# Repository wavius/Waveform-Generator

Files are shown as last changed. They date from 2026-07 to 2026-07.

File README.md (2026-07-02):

# Waveform-Generator

A power supply and waveform generator PCB. View the [Schematic and Layout (PDF)](./WAVEFORM_GENERATOR.pdf).

- +12V, -12V, +5V, and +3V3 DC power rails.
- Sine, square, and triangle signal outputs using the AD9833 IC.
- 45 W USB-C input for power delivery using the IP2721 IC.
- Integrated STM32F030C8T6 microcontroller for control.

<br>
<div align="left">
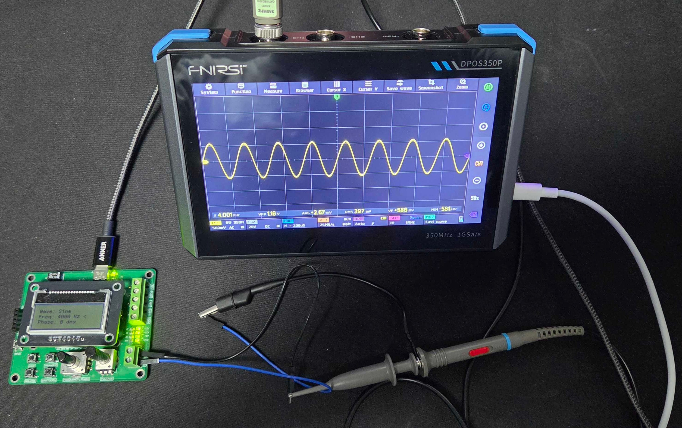
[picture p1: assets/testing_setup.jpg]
Testing Setup
  
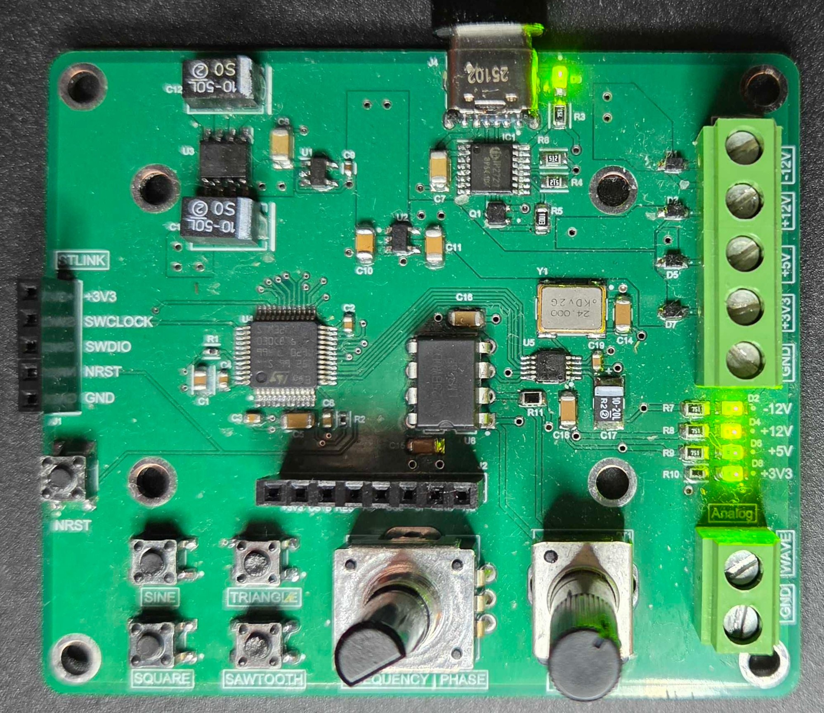
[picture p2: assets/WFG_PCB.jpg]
Waveform Generator Assembled PCB
  
</div>
<br>

## Features

### Power Supply

- **Screw Terminals**: +12V, -12V, +5V, and +3V3 DC power rails.

    <br>
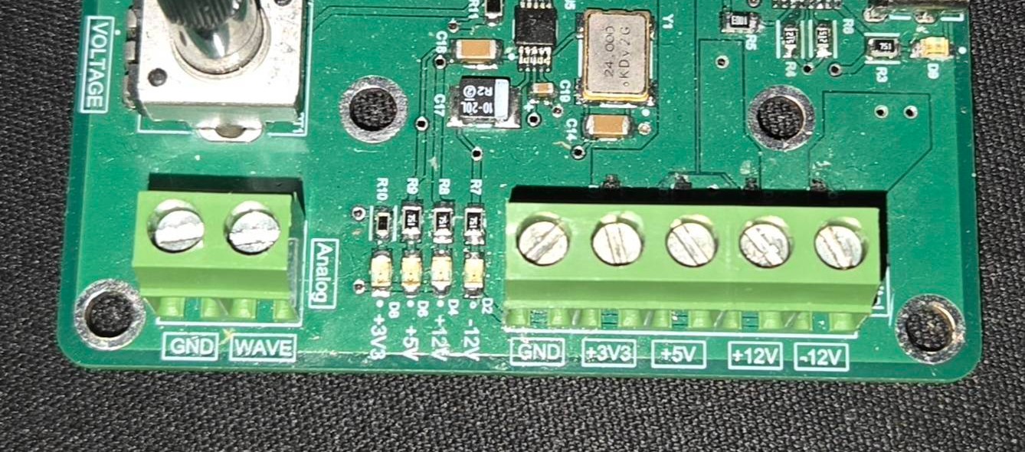
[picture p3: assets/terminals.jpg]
Screw Terminals
    
    <br>

### Signal Output

- **Waveform**: Toggle between sine, square, and triangle waveforms using the buttons. Note that the Sawtooth wave is unsupported by the AD9833 (oops), so the button toggles a half-frequency square wave instead.

    <br>
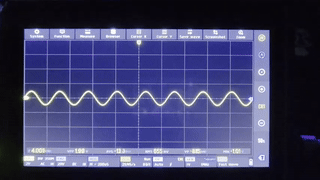
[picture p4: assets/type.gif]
Waveform Type
    
    <br>

- **Frequency and Phase**: Control the output frequency and phase using the rotary encoder.

    <br>
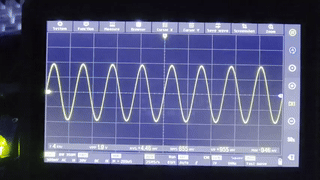
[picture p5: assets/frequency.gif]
Frequency Control
    
    <br>

- **Amplitude**: Tune the output analog voltage amplitude using the potentiometer.

    <br>
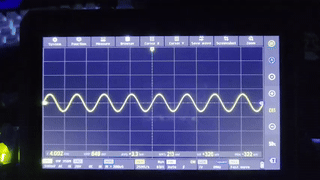
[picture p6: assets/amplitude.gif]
Amplitude Control
    
    <br>

### System Interface

- **Display**: LCD interface header for real-time waveform and parameter display.

    <br>
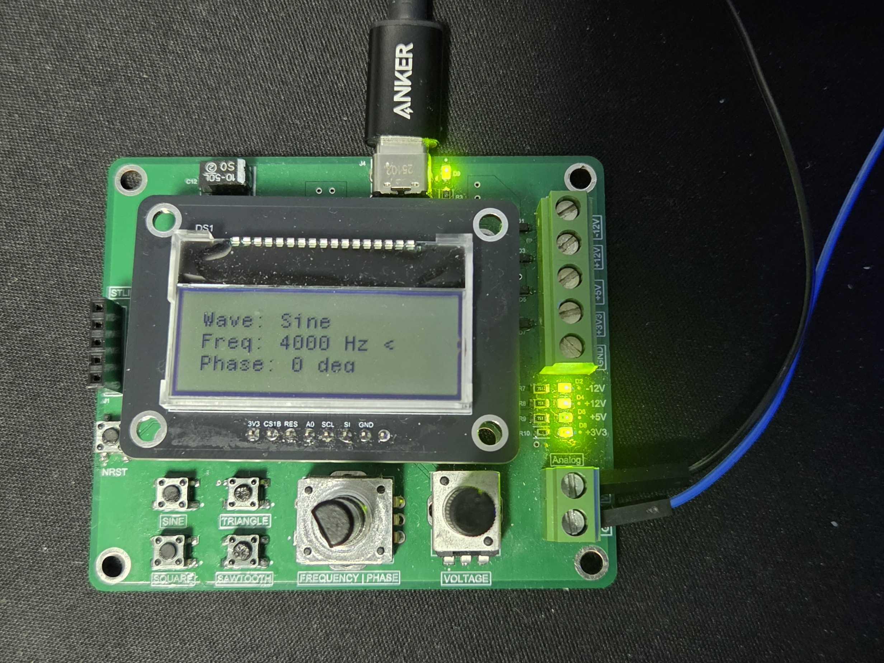
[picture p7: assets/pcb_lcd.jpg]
PCB LCD Display
    
    <br>

- **Control**: STM32F030C8T6 microcontroller with an ST-LINK interface header for programming and testing.

    <br>
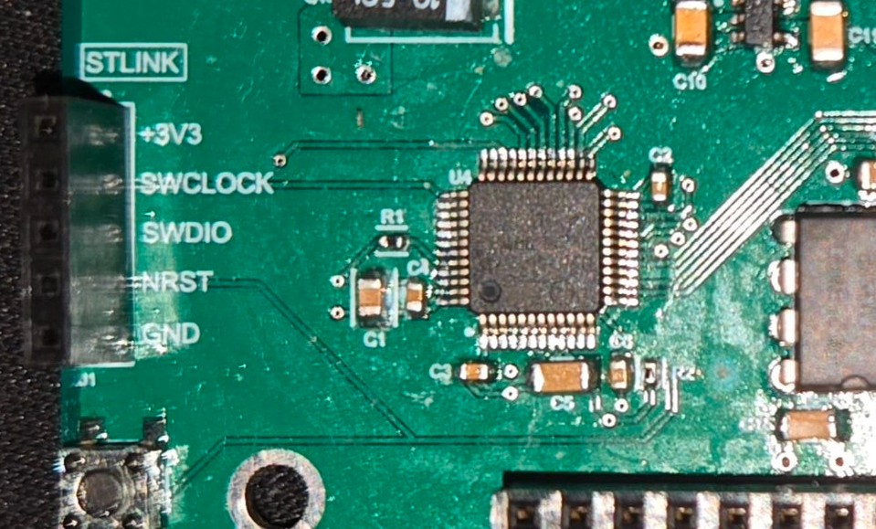
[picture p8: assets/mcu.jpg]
MCU
    
    <br>

## Source

### Firmware

The firmware is located in the [STM32 Project](./STM32%20Project) folder. It is written in C and uses the STM32 HAL libraries. Interrupts are used for the rotary encoder and buttons.

It can be opened and compiled using [STM32CubeIDE](https://www.st.com/en/development-tools/stm32cubeide.html). To upload the firmware to the device, use an ST-LINK V2, such as the one found on a NUCLEO board, and [STM32CubeProgrammer](https://www.st.com/en/development-tools/stm32cubeprogrammer.html).

### Design Files

The PCB design files are available in the [Altium Files](./Altium%20Files) folder. It is a 4-layer PCB with separate power and signal stages to minimize noise.

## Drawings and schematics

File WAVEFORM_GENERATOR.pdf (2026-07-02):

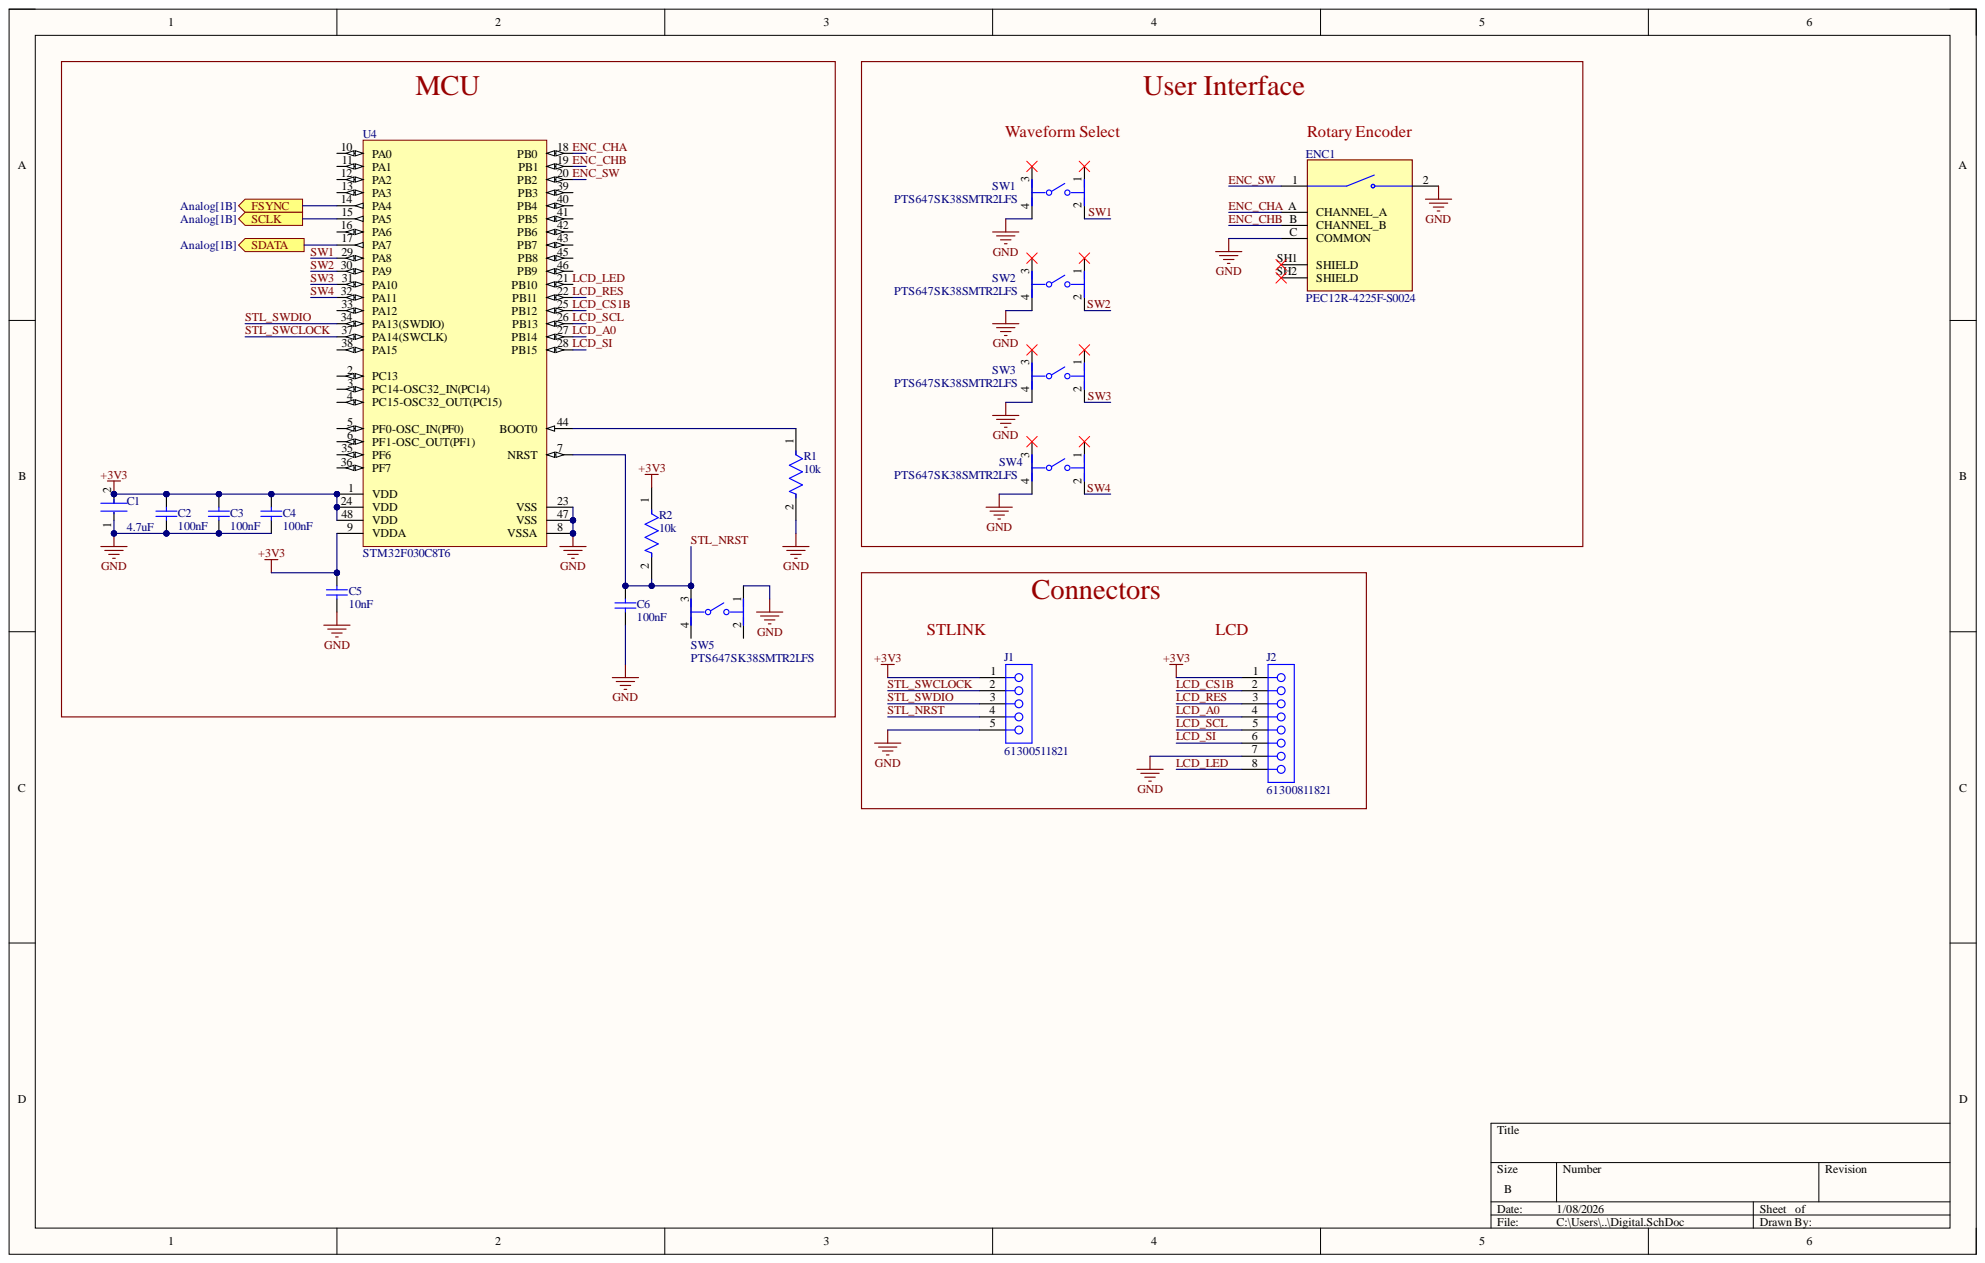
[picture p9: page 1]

2 4
4 8 | 4

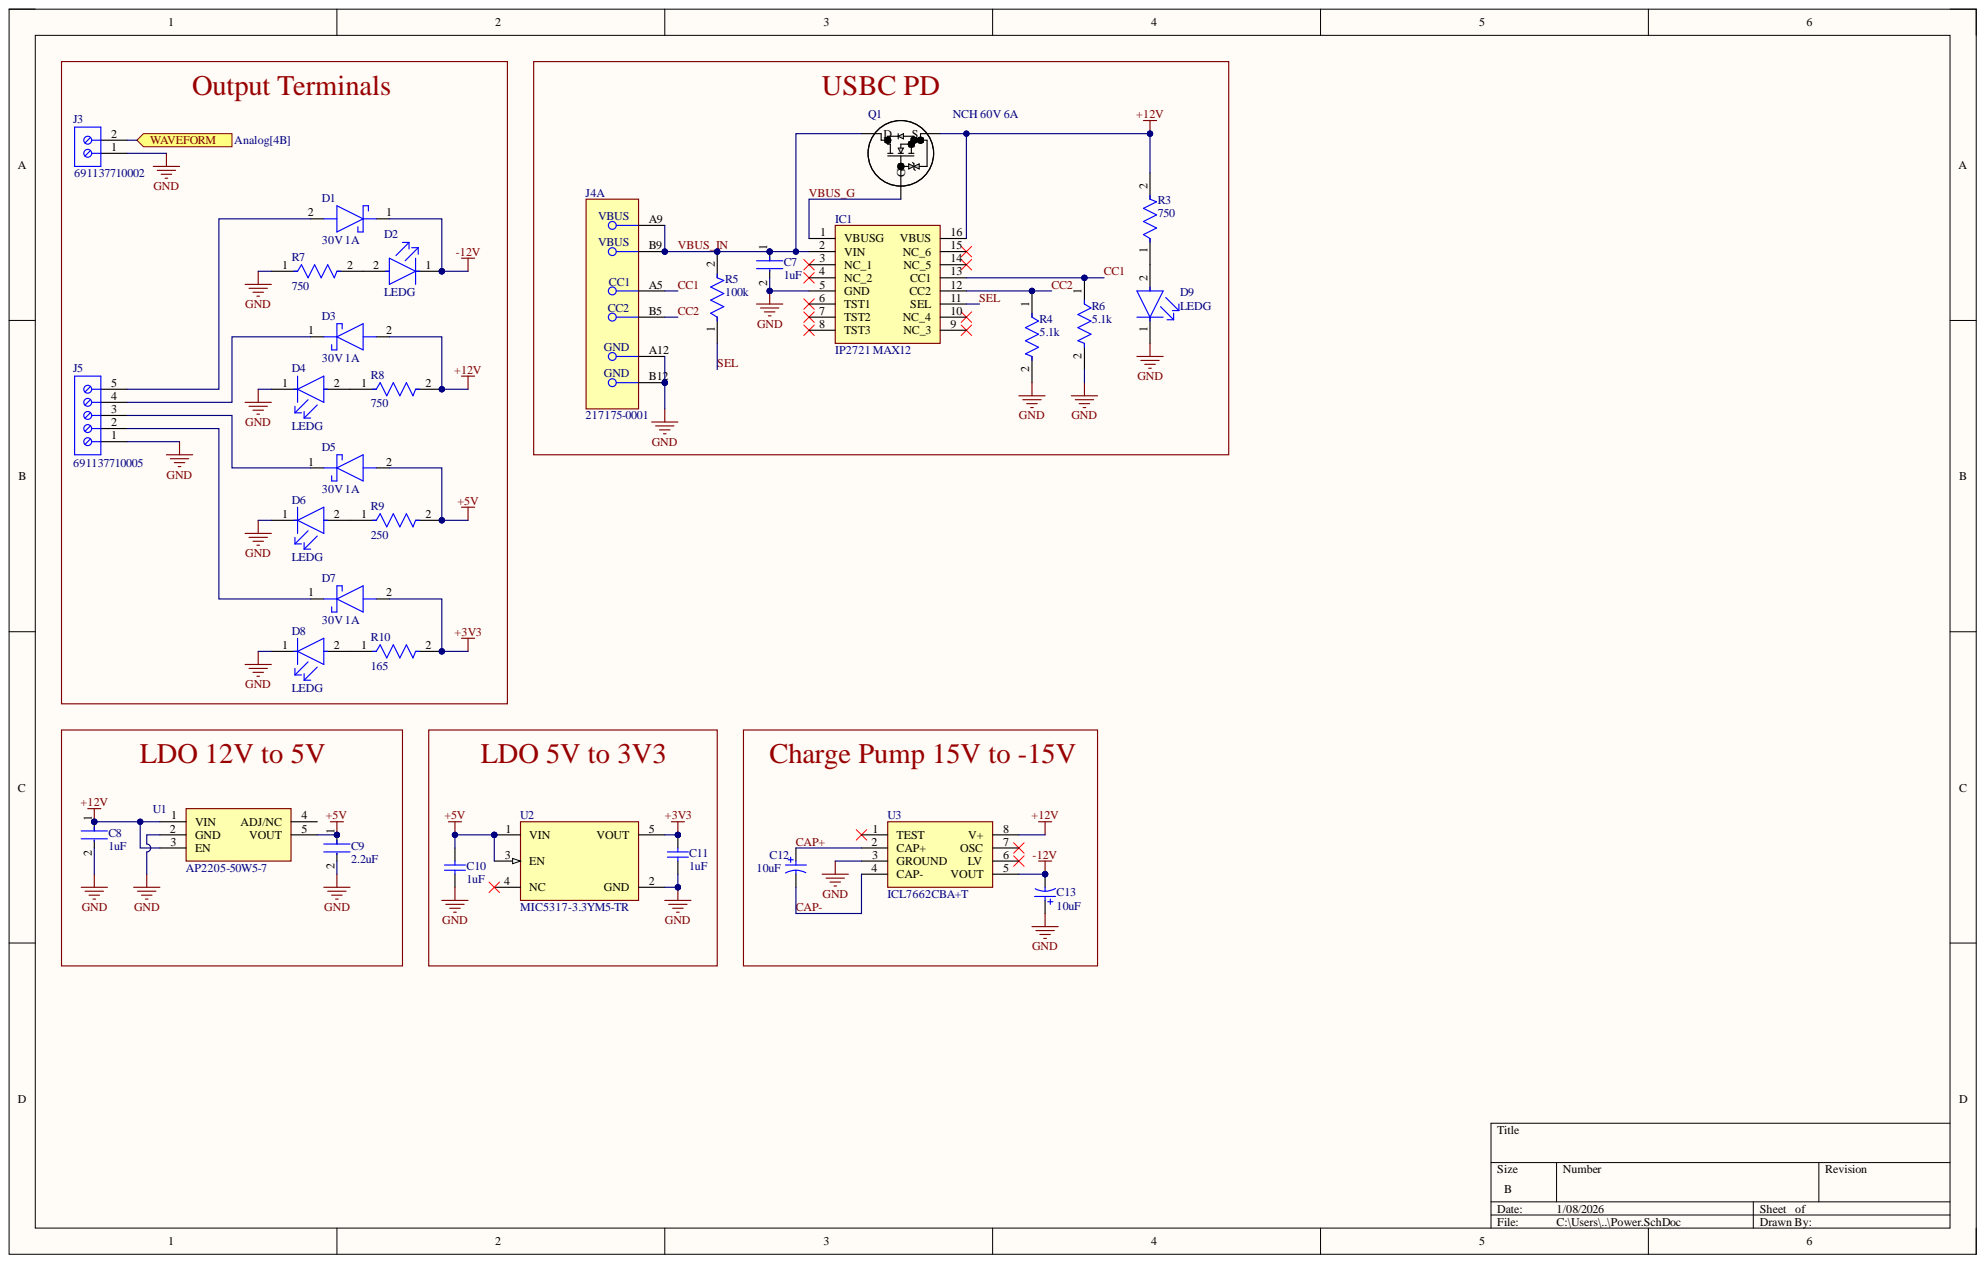
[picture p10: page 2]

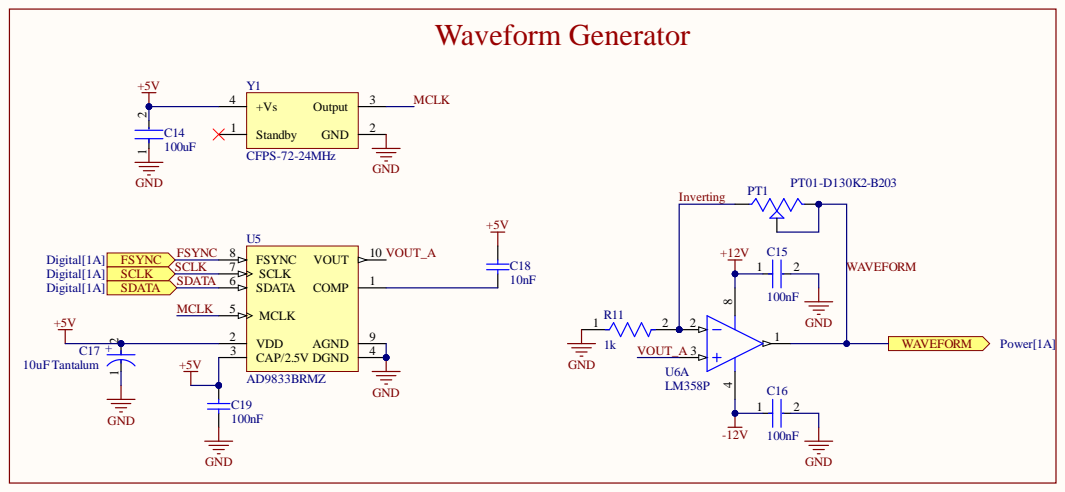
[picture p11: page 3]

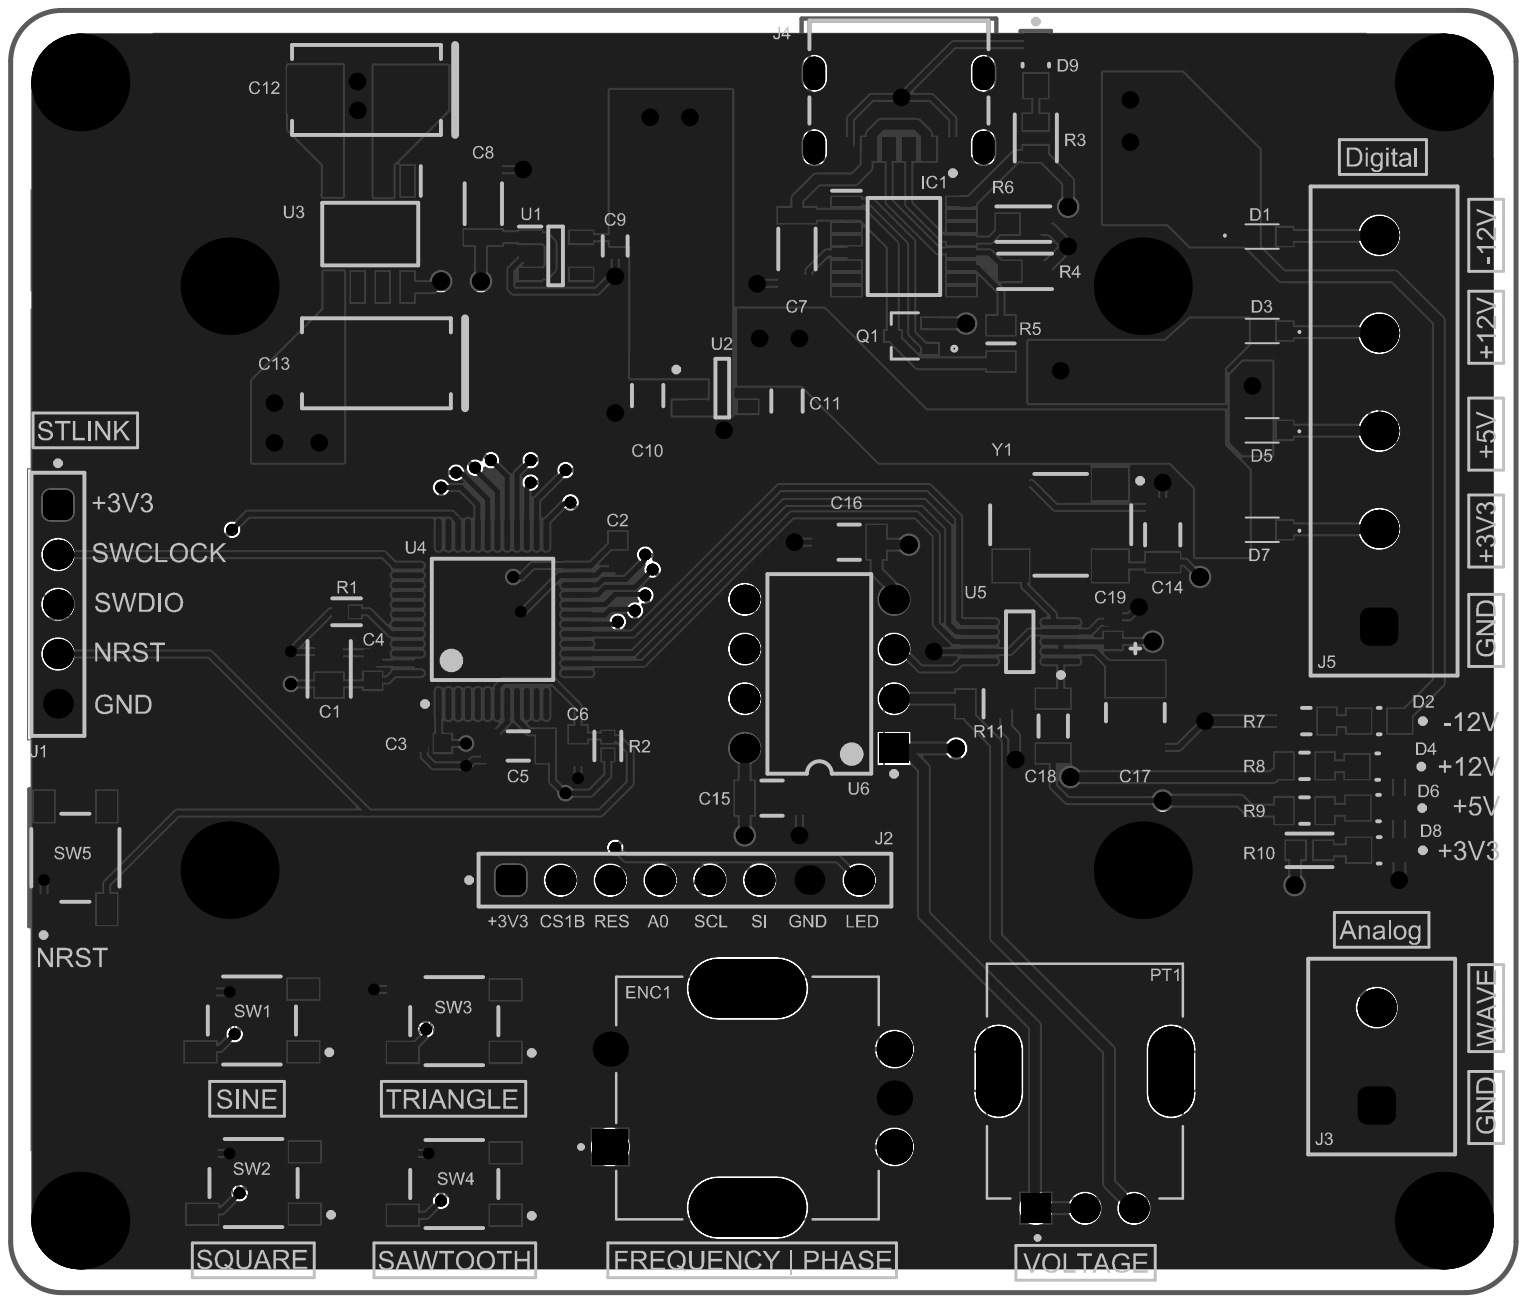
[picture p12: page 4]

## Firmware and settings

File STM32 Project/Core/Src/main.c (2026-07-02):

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
/* Includes ------------------------------------------------------------------*/
#include "main.h"

/* USER CODE BEGIN Includes */
#include "ad9833.h"
#include "st7565r.h"
#include <stdio.h>
/* USER CODE END Includes */

/* USER CODE BEGIN PTD */
enum Mode {
  MODE_FREQUENCY,
  MODE_PHASE
};
/* USER CODE END PTD */

/* USER CODE BEGIN PD */
#define AD9833_FREQ_MAX 100000ULL // 100 kHz
#define AD9833_FREQ_MIN 1ULL      // 1 Hz
#define AD9833_FREQ_STEP 1000ULL  // 1 kHz
/* USER CODE END PD */


/* USER CODE BEGIN PV */
uint32_t AD9833_Frequency = 1000; // 1 kHz
uint32_t AD9833_Phase = 0;        // 0 degrees
enum Mode AD9833_Mode = MODE_FREQUENCY;
AD9833_Waveform current_wave = AD9833_WAVEFORM_SINE;
/* USER CODE END PV */

void SystemClock_Config(void);
static void MX_GPIO_Init(void);
/* USER CODE BEGIN PFP */
void UpdateLCD(void);
/* USER CODE END PFP */

/**
  * @brief  The application entry point.
  * @retval int
  */
int main(void)
{

  /* MCU Configuration--------------------------------------------------------*/

  /* Reset of all peripherals, Initializes the Flash interface and the Systick. */
  HAL_Init();

  /* Configure the system clock */
  SystemClock_Config();

  /* Initialize all configured peripherals */
  MX_GPIO_Init();
  /* USER CODE BEGIN 2 */
  st7565r_Init();

  // Initialize AD9833 and generate a 1kHz sine wave
  AD9833_Init();
  AD9833_SetConfigF0P0(1000.0f, 0.0f, AD9833_WAVEFORM_SINE);
  /* USER CODE END 2 */

  /* Infinite loop */
  /* USER CODE BEGIN WHILE */
  while (1) {
    UpdateLCD();
    HAL_Delay(100);
    /* USER CODE END WHILE */

    /* USER CODE BEGIN 3 */
  }
  /* USER CODE END 3 */
}

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
/* USER CODE BEGIN 4 */
void UpdateLCD(void)
{
    char buf[32];
    st7565r_Fill(Black);
    
    // Waveform Type
    st7565r_SetCursor(0, 0);
    switch (current_wave) {
        case AD9833_WAVEFORM_SINE:        st7565r_WriteString("Wave: Sine", Font_7x10, White); break;
        case AD9833_WAVEFORM_TRIANGLE:    st7565r_WriteString("Wave: Triangle", Font_7x10, White); break;
        case AD9833_WAVEFORM_SQUARE:      st7565r_WriteString("Wave: Square", Font_7x10, White); break;
        case AD9833_WAVEFORM_SQUARE_HALF: st7565r_WriteString("Wave: Sq Half", Font_7x10, White); break;
    }

    // Frequency
    st7565r_SetCursor(0, 12);
    sprintf(buf, "Freq: %lu Hz %s", (unsigned long)AD9833_Frequency, (AD9833_Mode == MODE_FREQUENCY) ? "<" : "");
    st7565r_WriteString(buf, Font_7x10, White);

    // Phase
    st7565r_SetCursor(0, 24);
    sprintf(buf, "Phase: %lu deg %s", (unsigned long)AD9833_Phase, (AD9833_Mode == MODE_PHASE) ? "<" : "");
    st7565r_WriteString(buf, Font_7x10, White);

    st7565r_UpdateScreen();
}

void HAL_GPIO_EXTI_Callback(uint16_t GPIO_Pin)
{
  static uint32_t last_interrupt_time = 0;
  uint32_t interrupt_time = HAL_GetTick();

  // debounce 50ms
  if (interrupt_time - last_interrupt_time > 50)
  {

    switch (GPIO_Pin)
    {
      case SW1_Pin:
        current_wave = AD9833_WAVEFORM_SINE;
        AD9833_SetWaveform(current_wave);
        break;
      case SW2_Pin:
        current_wave = AD9833_WAVEFORM_SQUARE;
        AD9833_SetWaveform(current_wave);
        break;
      case SW3_Pin:
        current_wave = AD9833_WAVEFORM_TRIANGLE;
        AD9833_SetWaveform(current_wave);
        break;
      case SW4_Pin:
        current_wave = AD9833_WAVEFORM_SQUARE_HALF;
        AD9833_SetWaveform(current_wave);
        break;
        
      case ENC_CHA_Pin: {
        static uint32_t last_enc_time = 0;
        if (interrupt_time - last_enc_time > 150) {
            last_enc_time = interrupt_time;
            if (AD9833_Mode == MODE_FREQUENCY) {
              // cw: channel signals are opposite values    
              if (HAL_GPIO_ReadPin(ENC_CHB_GPIO_Port, ENC_CHB_Pin) == GPIO_PIN_SET) { 
            // increase frequency
            if (AD9833_Frequency == AD9833_FREQ_MIN) {
              AD9833_Frequency = AD9833_FREQ_STEP; // Snap from 1Hz to 1000Hz
            } else if (AD9833_Frequency <= AD9833_FREQ_MAX - AD9833_FREQ_STEP) {
              AD9833_Frequency += AD9833_FREQ_STEP;
            } else {
              AD9833_Frequency = AD9833_FREQ_MAX;
            }
          // ccw: channel signals are same values
          } else {
            // decrease frequency
            if (AD9833_Frequency <= AD9833_FREQ_STEP) {
              AD9833_Frequency = AD9833_FREQ_MIN; // Snap down to 1Hz
            } else {
              AD9833_Frequency -= AD9833_FREQ_STEP;
            }
          }
          AD9833_SetFrequency_0((float)AD9833_Frequency);
        } 
        else if (AD9833_Mode == MODE_PHASE) {
          // cw: channel signals are opposite values    
          if (HAL_GPIO_ReadPin(ENC_CHB_GPIO_Port, ENC_CHB_Pin) == GPIO_PIN_SET) { 
            // increase phase 
            AD9833_Phase = (AD9833_Phase + 45) % 360;
          // ccw: channel signals are same values
          } else {
            // decrease phase
            if (AD9833_Phase < 45) {
              AD9833_Phase = 360 - (45 - AD9833_Phase);
            } else {
              AD9833_Phase -= 45;
            }
          }
          AD9833_SetPhase_0((float)AD9833_Phase);
        }
        } // end of encoder debounce
        break;
      }
      case ENC_SW_Pin:
        // Rotary encoder button pressed
        AD9833_Mode = !AD9833_Mode;
        AD9833_SetPhase_0((float)AD9833_Phase);
        break;
    }
  }
  last_interrupt_time = interrupt_time;
}
/* USER CODE END 4 */
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


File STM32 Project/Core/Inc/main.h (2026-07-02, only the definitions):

#define AD_FSYNC_Pin GPIO_PIN_4
#define AD_FSYNC_GPIO_Port GPIOA
#define AD_SCLK_Pin GPIO_PIN_5
#define AD_SCLK_GPIO_Port GPIOA
#define AD_SDAT_Pin GPIO_PIN_7
#define AD_SDAT_GPIO_Port GPIOA
#define ENC_CHA_Pin GPIO_PIN_0
#define ENC_CHA_GPIO_Port GPIOB
#define ENC_CHA_EXTI_IRQn EXTI0_1_IRQn
#define ENC_CHB_Pin GPIO_PIN_1
#define ENC_CHB_GPIO_Port GPIOB
#define ENC_SW_Pin GPIO_PIN_2
#define ENC_SW_GPIO_Port GPIOB
#define ENC_SW_EXTI_IRQn EXTI2_3_IRQn
#define LCD_RES_Pin GPIO_PIN_11
#define LCD_RES_GPIO_Port GPIOB
#define LCD_CS_Pin GPIO_PIN_12
#define LCD_CS_GPIO_Port GPIOB
#define LCD_SC_Pin GPIO_PIN_13
#define LCD_SC_GPIO_Port GPIOB
#define LCD_RS_Pin GPIO_PIN_14
#define LCD_RS_GPIO_Port GPIOB
#define LCD_SI_Pin GPIO_PIN_15
#define LCD_SI_GPIO_Port GPIOB
#define SW1_Pin GPIO_PIN_8
#define SW1_GPIO_Port GPIOA
#define SW1_EXTI_IRQn EXTI4_15_IRQn
#define SW2_Pin GPIO_PIN_9
#define SW2_GPIO_Port GPIOA
#define SW2_EXTI_IRQn EXTI4_15_IRQn
#define SW3_Pin GPIO_PIN_10
#define SW3_GPIO_Port GPIOA
#define SW3_EXTI_IRQn EXTI4_15_IRQn
#define SW4_Pin GPIO_PIN_11
#define SW4_GPIO_Port GPIOA
#define SW4_EXTI_IRQn EXTI4_15_IRQn

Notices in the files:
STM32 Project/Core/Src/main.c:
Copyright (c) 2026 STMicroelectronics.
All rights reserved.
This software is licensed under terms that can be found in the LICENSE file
